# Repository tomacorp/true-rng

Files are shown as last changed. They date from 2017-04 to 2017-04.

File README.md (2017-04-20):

# true-rng

Hardware design to create a true-random number generator.
See https://hackaday.io/project/21054-true-random-number-generator for details.

The EAGLE files are incomplete and unchecked. I have hand-edited the symbols
and footprints based on miscellaneous EAGLE data that I have found spread around. It is not to be trusted yet! It needs checking. Also the electrical design has not been prototyped or simulated.

__noise_amplifier.xlsx__

The spreadsheet noise_amplifier.xlsx has the design equations and
documentation for the analog circuit design. I can explain the design process
in more detail in the hackaday.io project if anyone is interested.
The technique could be used to design buffer amplifiers for other types of sensors.

__vreg_local.lbr__

A local library with symbols, footprints, and maps.

__analog_rng2.sch__

The schematic so far.

__analog_rng2.brd__

The board layout, work-in-progress.

__LICENSE__

Copyright 2017 Tom Anderson

Permission is hereby granted, free of charge, to any person obtaining a copy of this software and associated documentation files (the "Software"), to deal in the Software without restriction, including without limitation the rights to use, copy, modify, merge, publish, distribute, sublicense, and/or sell copies of the Software, and to permit persons to whom the Software is furnished to do so, subject to the following conditions:

The above copyright notice and this permission notice shall be included in all copies or substantial portions of the Software.

THE SOFTWARE IS PROVIDED "AS IS", WITHOUT WARRANTY OF ANY KIND, EXPRESS OR IMPLIED, INCLUDING BUT NOT LIMITED TO THE WARRANTIES OF MERCHANTABILITY, FITNESS FOR A PARTICULAR PURPOSE AND NONINFRINGEMENT. IN NO EVENT SHALL THE AUTHORS OR COPYRIGHT HOLDERS BE LIABLE FOR ANY CLAIM, DAMAGES OR OTHER LIABILITY, WHETHER IN AN ACTION OF CONTRACT, TORT OR OTHERWISE, ARISING FROM, OUT OF OR IN CONNECTION WITH THE SOFTWARE OR THE USE OR OTHER DEALINGS IN THE SOFTWARE.

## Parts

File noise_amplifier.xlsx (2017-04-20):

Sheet: requirements
Low Noise Design for Measuring Resistor Noise
 |  |  | Component value or specification | Calculation
Noise resistor value | 100000 | Ohm | 100K
Noise resistor voltage noise | 4.047715405e-08 | V/sqrt(Hz) |  | 0.128*sqrt(Resistance)= Resistor voltage noise
Noise resistor shunt capacitance | 1e-11 | F | 10pF
Source bandwidth | 132629.1192 | Hz |  | Estimated based on 3dB bandwidth. Actual noise bandwidth should be simulated
Amplifier capacitance | 2e-12 | F | OPA4134 specification
Amplifer voltage noise | 8e-09 | V/sqrt(Hz) | OPA4134 specification
Amplifier current noise | 3e-15 | A/sqrt(Hz) | OPA4134 specification
Feedback noise | 2.359829851e-09 | V/sqrt(Hz) |  | Noise from the physics package that is sent back to the amplifier feedback
Amplifier input noise | 8.346184573e-09 | V/sqrt(Hz) |  | Voltage and current noise at the amplifier that is not from the physics package
Total input noise | 4.132866798e-08 | V/sqrt(Hz) |  | Add up the physics package noise and the amplifier noise
RMS input noise | 2.084704051e-05 | V RMS |  | Total RMS noise accounts for the noise bandwidth
Physics package noise to amp noise ratio | 13.7144397 | dB |  | Key performance metric. Determines how well the physics package noise dominates the measured noise.
Input stage feedback resistor | 2200 | Ohm | 2.2K
Input stage feedback shunt resistor | 402 | Ohm | 4.02K
Input stage gain | 6.472636816 | V/V |  | Feedback equation
Input offset voltage, max | 0.003 | V | OPA4134 specification
Input offset current, max | 5e-11 | A | OPA4134 specification
Output offset voltage | 0.15025 | V |  | Input offset voltage gets multiplied by gain
Amplifier gain-bandwidth | 8000000 | Hz | OPA4134 specification
Bandwidth at gain | 1235972.329 | Hz |  | Closed-loop 3dB bandwidth frequency
Loop gain at sensor bandwidth | 9.319011813 | V/V |  | How well the amplifier tracks the highest frequency noise from the physics package
Amplifier input noise | 1.505119045e-05 | V |  | RMS noise
Amplifier output noise | 9.742088941e-05 | V |  | Amplified noise
Differential input resistor | 2200 | Ohm | 2.2K
Differential feedback resistor | 100000 | Ohm | 100K
Differential stage gain | 45.45454545 | V/V |  | Feedback equation
Differential stage adding noise factor | 1.414213562 | V/V |  | Noise adds as the sqrt(sum of the squares)
Differential stage output voltage | 0.006262451957 | V |  | Amplified noise at diff amp output
Differential stage bandwidth | 176000 | Hz |  | This bandwidth should be greater than the input stage bandwidth
Output stange input resistor | 2200 | Ohm | 2.2K
Output stage feedback resistor | 100000 | Ohm | 100K
Output stage gain | 45.45454545 | V/V |  | Feedback equation
Output stage voltage | 0.2846569071 | V |  | RMS signal level at the amplifier output
Output stage voltage Pk-Pk | 1.707941443 | V |  | Peak-to-peak signal level at the amplifier output
Output stage amplifier headroom | 1.2 | V | OPA4134 specification
Output stage supply voltage | 5 | V | Supply choice
Output stage maximum signal | 2.6 | V |  | Margin needed to keep noise signal from clipping
Output stage voltage margin | 0.8920585571 | V |  | Amount of margin in this design to keep noise signal from clipping.
Noise DC coupling capacitor | 1e-06 | F | 1uF
Noise DC coupling capacitor load | 2200 | Ohm | 2.2K
Noise low frequency corner | 72.34315595 | Hz |  | RC frequency of DC block
OPA4134 quiescent current per amp | 0.005 | A | OPA4134 specification
LM2903 quieschent current per comparator | 0.0025 | A | LM2903 specification
Output pullup resistor current | 0.002272727273 | A |  | Pullup resistor current
Total current draw | 0.02954545455 | A |  | Includes quad opamp, comparators, and pullup resistors
Doubler frequency | 80000 | Hz | LM2776 specification
Doubler Capacitor ESR | 0.01 | Ohm | Ceramic 10uF Capacitor
Doubler Capacitor value | 1e-05 | F | 10uF
Vripple | 0.03752272727 | V |  | Datasheet formula for calculating switching ripple voltage
10V supply dropping voltage, nom | 2 | V | Supply choice
10V supply dropping resistor, max | 67.69230769 | Ohm |  | Biggest resistor to get nominal supply voltage drop
10V supply dropping resistor | 49.9 | Ohm | 49.9 Ohm
5V regulator input capacitor | 1e-05 | F | 10uF
RC filter corner frequency | 318.9477817 | Hz |  | RC frequency of DC block
RC filter switching gain | 0.003986847272 | V/V |  | Attenuation at switching frequency due to RC filter
RC filter switching attenuation | 47.98740802 | dB |  | Attenuation at switching frequency due to RC filter in dB
Vripple after filter | 0.0001495973829 | V |  | Voltage ripple at output of RC filter
P2R5V bead inductance | 1e-07 | H | BLM18BB600SN1D specification
P2R5V bead impedance at 100MHz | 62.83185307 | jOhms |  | Nominal bead impedance at 100MHz is used for selecting and comparing beads
P2R5V net capacitance | 9.1e-06 | F | 10uF -10% + 0.1iF
P2R5V net resonant frequency | 166839.7135 | Hz |  | Network LC-resonant frequency
P2R5V net Q | 0.7071067812 |  |  | Desired Q of resonance (overdamped)
P2R5V damping resistance needed in bead | 0.1482498633 |  |  | DC resistance in bead that is sufficient to provide desired Q of resonance

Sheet: components
 | Description | Cost | Cost | Digi-Key Part No | MPN | Mfgr | SBA PN | Description | Notes
 |  | 1's | 100's
opamp | OPA4134 | 4.59 | 3.37 | 296-26284-1-ND | OPA4134UA/2K5 | TI |  | IC OPAMP AUDIO 8MHZ 14SOIC
 | OPA2134 | 3.65 | 2.6894 | 296-22024-1-ND | OPA2134UA/2K5 | TI |  | IC OPAMP AUDIO 8MHZ 8SOIC | Dual is not so much cheaper that two dual is a better option, even if one of the duals could be much cheaper.
comparator | CMOS Dual Comparator | 0.39 | 0.2175 | 296-1012-1-ND | LM2903DR | TI |  | Comparator Differential CMOS, MOS, Open-Collector, TTL 8-SOIC
Precision Resistors:
noise resistor | 100K 0.1% thin film 0805 | 0.35 | 0.1219 | YAG1759CT-ND | RT0805BRD07100KL | Yageo |  | RES SMD 100K OHM 0.1% 1/8W 0805
 |  | 0.41 | 0.1182 | P100KDACT-ND | ERA-6AEB104V | Panasonic |  | RES SMD 100K OHM 0.1% 1/8W 0805 | Thin Film Automotive Grade
feedback resistor, first stage | 49.9K 0.1% thin film 0805 |  |  | RG20P49.9KBCT-ND | RG2012P-4992-B-T5 | Susumu |  | RES SMD 49.9K OHM 0.1% 1/8W 0805
 |  |  |  | YAG1912CT-ND | RT0805BRD0749K9L | Yageo |  | RES SMD 49.9K OHM 0.1% 1/8W 0805
shunt resistor, first stage | 402 OHM 0.1% thin film 0805 | 0.39 | 0.1126 | P402DACT-ND | ERA-6AEB4020V | Panasonic |  | RES SMD 402 OHM 0.1% 1/8W 0805 | Thin Film Automotive Grade
 |  | 0.61 | 0.2623 | A110505CT-ND | 8-2176091-0 | TE
shunt resistor, first stage | 1K 0.1% thin film 0805 |  |  | P1.0KDACT-ND | ERA-6AEB102V | Panasonic |  | RES SMD 1K OHM 0.1% 1/8W 0805
 |  |  |  | RG20P1.0KBCT-ND | RG2012P-102-B-T5 | Susumu |  | RES SMD 1K OHM 0.1% 1/8W 0805
differential input resistor, diff stage | 2.2K 0.1% thin film 0805 | 0.41 | 0.1182 | P2.2KDACT-ND | ERA-6AEB222V | Panasonic |  | RES SMD 2.2K OHM 0.1% 1/8W 0805 | Thin Film Automotive Grade
 |  |  |  | RG20P2.2KBCT-ND | RG2012P-222-B-T5 | Susumu
 |  |  |  | YAG1853CT-ND | RT0805BRD072K2L | Yageo
Voltage inverter | IC REG SWTCHD CAP INV 6SOT23 | 1.1 | 0.7676 | 296-43957-1-ND | LM2776DBVR | TI |  | IC REG SWTCHD CAP INV 6SOT23 | 80kHz, needs 1 external Schottky diode
Positive voltage regulator | IC REG LDO 2.5V 0.3A 5SOT23 | 0.41 |  | 296-38491-1-ND | TLV73325PDBVT | TI |  | IC REG LDO 2.5V 0.3A 5SOT23
Negative voltage regulator | IC REG LDO -2.5V 0.2A SOT23-5 | 2.87 |  | 296-39479-1-ND | TPS72325DBVR | TI |  |  | Negative regulators are expensive!
Power opamp for neg regulator | LMC7101AYM5-TR | Not so good PSRR. Cheap. |  |  |  |  |  |  | Power opamps don't make good negative regulators, either
0.1uF X7R | CAP CER 0.1UF 25V 10% X7R 0603 | 0.1 | 0.0091 | 490-1524-1-ND | GRM188R71E104KA01D | Murata | 8 | CAP CER 0.1UF 25V 10% X7R 0603
1uF X7R | CAP CER 1UF 25V 10% X7R 1206 | 0.2 | 0.0683 | 490-5860-1-ND | GRM31MR71E105KA01L | Murata | 171 | CAP CER 1UF 25V 10% X7R 1206
22pF NP0 | CAP CER 22PF 50V 5% NP0 0603 | 0.1 | 0.00302 | 490-1411-1-ND | GRM1885C1H220JA01D | Murata | 10 | CAP CER 22PF 50V 5% NP0 0603
4.7uF TANT | CAP TANT 4.7UF 20V 20% 1206 | 0.63 | 0.2919 | 478-5799-1-ND | TAJA475M020RNJ | AVX | 12 | CAP TANT 4.7UF 20V 20% 1206
10uF X7R 10V | CAP CER 10UF 10V X7R 1206 | 0.26 | 0.1026 | 490-3371-1-ND | GRM31CR71A106KA01L | Murata |  | CAP CER 10UF 10V X7R 1206
10uF X7R 16V | CAP CER 10UF 16V X7R 1206 | 0.43 | 0.1811 | 490-3911-1-ND | GRM31CR71C106KAC7L | Murata |  | CAP CER 10UF 16V X7R 1206
100K 1% | RES 100K OHM 1/10W 1% 0603 SMD | 0.1 | 0.0129 | 541-100KHCT-ND | CRCW0603100KFKEA | Vishay/Dale | 161 | RES 100K OHM 1/10W 1% 0603 SMD
Mini USB Connector | CONN RECEPT MINIUSB R/A 5POS SMD | 1.03 | 0.7783 | WM5461CT-ND | 67503-1020 | Molex | 32 |  | 2 THT pins for mechanical stability
Safety Components: Fuse and MOV
Resetable fuse | PTC .50A 15VDC RESETTABLE 1812L | 0.51 | 0.334 | F2150CT-ND | 1812L050PR | Littlefuse | 39 | PTC .50A 15VDC RESETTABLE 1812L | Sustains 500mA at 5V
 | PTC RESTTBLE 0.20A 9V CHIP 0805 |  |  | 507-1517-1-ND | 0ZCE0020FF2G | Bel Fuse | 169 | OBSOLETE, but preferred at SBA
MOV 5.5V DC pass | VARISTOR 8V 150A 1206 | 0.64 | 0.4017 | 495-7466-1-ND | B72520T40M62 | EPCOS(TDK) |  |  | Will not fire on 5.5V
Bead | FERRITE BEAD 60 OHM 0603 1LN | 0.1 | 0.0451 | 490-5247-1-ND | BLM18BB600SN1D | Murata |  | FERRITE BEAD 60 OHM 0603 1LN | DC resistance needed for damping
Schottky Power Diode | DIODE SCHOTTKY 20V 500MA SOD123 | 0.37 | 0.1589 | MBR0520LT1GOSCT-ND | MBR0520LT1G | ON Semiconductor |  | DIODE SCHOTTKY 20V 500MA SOD123
Highlighted parts are used in the design. Others are for comparison or reference.

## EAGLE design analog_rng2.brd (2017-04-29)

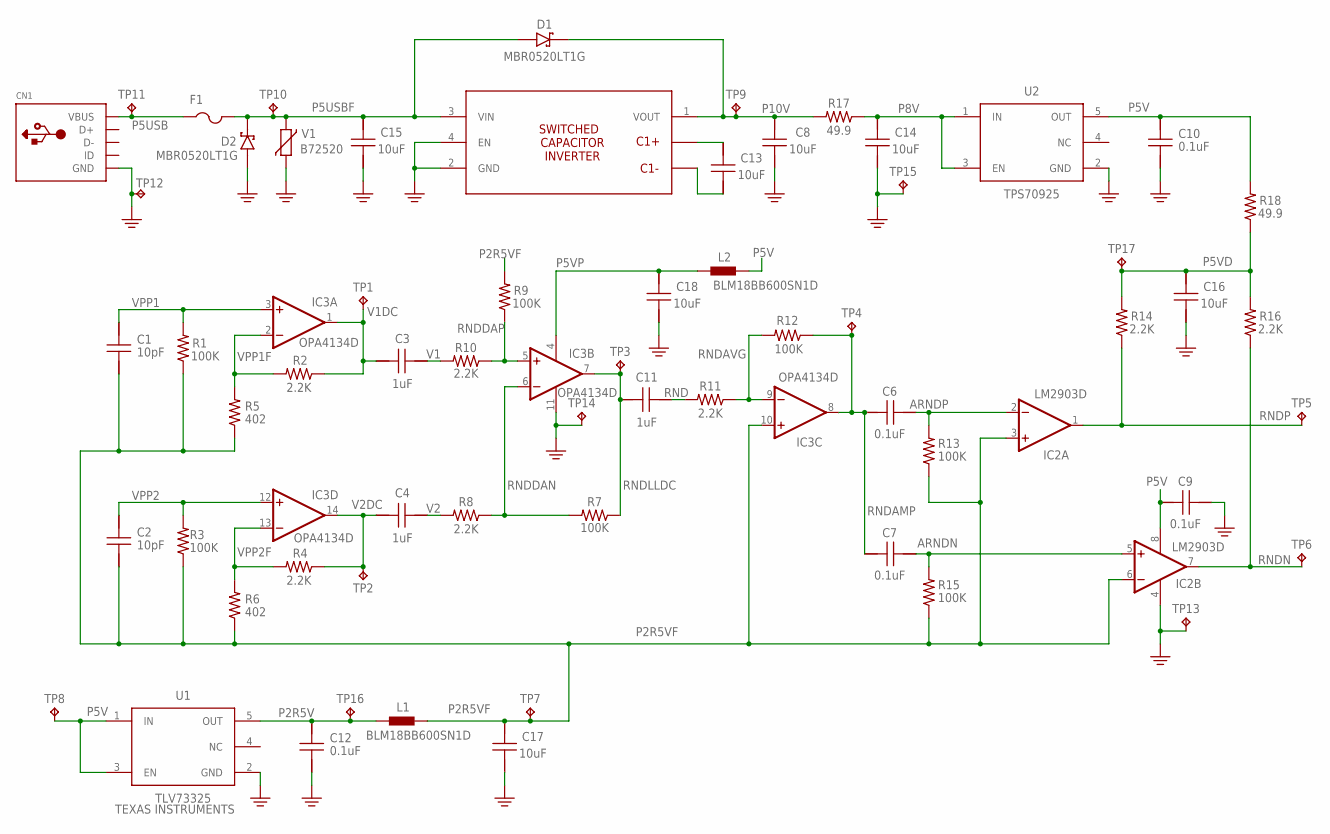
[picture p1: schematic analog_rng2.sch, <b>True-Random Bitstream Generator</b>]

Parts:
C1, C2: 10pF; C0603
C3, C4, C11: 1uF; C1206
C6, C7, C9, C10, C12: 0.1uF; C0603
C8, C13, C14, C15, C16, C17, C18: 10uF; C1206
CN1: USBMINIB; USB-MINIB
D1, D2: MBR0520LT1G; SOD-123
F1: PTCFUSE-1812; 1812
IC2: LM2903D; SO08
IC3: OPA4134D; SO14
L1, L2: BLM18BB600SN1D; R0805
R1, R3, R7, R9, R12, R13, R15: 100K; R1206
R2, R4, R8, R10, R11, R14, R16: 2.2K; R1206
R5, R6: 402; R1206
R17, R18: 49.9; R1206
TP1, TP2, TP3, TP4, TP5, TP6, TP7, TP8, TP9, TP10, TP11, TP12, TP13, TP14, TP15, TP16, TP17: TPPAD1-20; P1-20
U1: TLV73325; SOT23-5
U2: TPS70925; SOT23-5
U23423: LM277625; SOT23-6
V1: B72520; CT/CN1206

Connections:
ARNDN: C7.2, IC2.5 (+IN), R15.2
ARNDP: C6.2, IC2.2 (-IN), R13.2
unnamed: C13.1, U23423.5 (C1P)
unnamed: C13.2, U23423.6 (C1N)
P2R5V: C12.1, L1.1, TP16.TP, U1.5 (OUT)
P2R5VF: C1.2, C2.2, C17.1, IC2.3 (+IN), IC2.6 (-IN), IC3.10 (+IN), L1.2, R1.1, R3.1, R5.1, R6.1, R9.2, R13.1, R15.1, TP7.TP
P5USB: CN1.VBUS, F1.1, TP11.TP
P5USBF: C15.1, D1.A, D2.K, F1.2, TP10.TP, U23423.3 (VIN), V1.1
P5V: C9.1, C10.1, IC2.8 (V+), L2.2, R18.2, TP8.TP, U1.1 (IN), U1.3 (EN), U2.5 (OUT)
P5VD: C16.1, R14.2, R16.2, R18.1, TP17.TP
P5VP: C18.1, IC3.4 (V+), L2.1
P8V: C14.1, R17.1, U2.1 (IN), U2.3 (EN)
P10V: C8.1, D1.K, R17.2, TP9.TP, U23423.1 (VOUT)
PE: C8.2, C9.2, C10.2, C12.2, C14.2, C15.2, C16.2, C17.2, C18.2, CN1.GND, D2.A, IC2.4 (V-), IC3.11 (V-), TP12.TP, TP13.TP, TP14.TP, TP15.TP, U1.2 (GND), U2.2 (GND), U23423.2 (GND), U23423.4 (EN), V1.2
RND: C11.2, R11.2
RNDAMP: C6.1, C7.1, IC3.8 (OUT), R12.1, TP4.TP
RNDAVG: IC3.9 (-IN), R11.1, R12.2
RNDDAN: IC3.6 (-IN), R7.2, R8.1
RNDDAP: IC3.5 (+IN), R9.1, R10.1
RNDLLDC: C11.1, IC3.7 (OUT), R7.1, TP3.TP
RNDN: IC2.7 (OUT), R16.1, TP6.TP
RNDP: IC2.1 (OUT), R14.1, TP5.TP
V1: C3.2, R10.2
V1DC: C3.1, IC3.1 (OUT), R2.1, TP1.TP
V2: C4.2, R8.2
V2DC: C4.1, IC3.14 (OUT), R4.1, TP2.TP
VPP1: C1.1, IC3.3 (+IN), R1.2
VPP1F: IC3.2 (-IN), R2.2, R5.2
VPP2: C2.1, IC3.12 (+IN), R3.2
VPP2F: IC3.13 (-IN), R4.2, R6.2

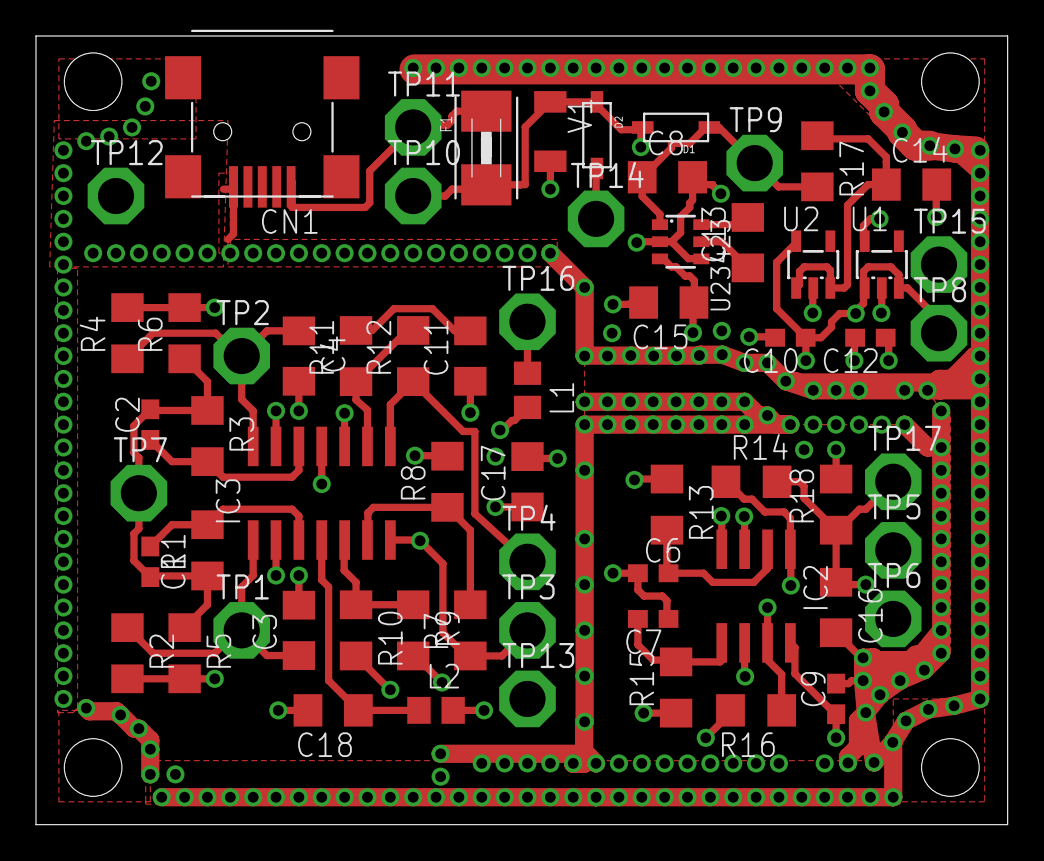
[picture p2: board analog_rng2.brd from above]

Board: 4 copper layers, 54.0 x 43.8 mm, 64 parts (0 on the bottom side), 30 nets.

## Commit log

2017-04-20 Initial version of design equations, schematic, and layout.
    [analog_rng2.brd, analog_rng2.sch, noise_amplifier.xlsx]
2017-04-29 More layout work done, finished first cut at copper layout
    [analog_rng2.brd, analog_rng2.sch]
